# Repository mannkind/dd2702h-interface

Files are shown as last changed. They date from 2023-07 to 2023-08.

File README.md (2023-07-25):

# Home Automation - DD2702H

A **quick and dirty** interface to the DD2702H remote.

Seriously. This is hacky hack hacky. But it's all hidden in a nice little case, so I don't really care.  
It requires removing the DD2702H from the stock case, soldering some wires to it, and hooking up an esp32.

## Build of Materials

* 1 - DD2702H remote
* 1 - Custom PCB
* 1 - Nekmit Dual Port Ultra Thin Flat USB Wall Charger
* 1 - Wemos D1 Mini (esp32)
* 2 - Strips of female connectors for Wemos D1 Mini
* 3 - 1k through-hole resistors
* 3 - 2N3904 PNP transistors
* 1 - DD2702H Remote
* 11 - Male pins; angled preferred
* Some wires to connect them

## Program

The [example yaml](program/dd2702h.yaml) for ESPHome contains all you should need to get started. 
ESPHome is awesome, and I'm lazy.

## PCB

I ordered the PCB from OSHPark.com by uploading the KiCAD files.
Turn-around time was a week, and the boards from OSHPark are high quality.

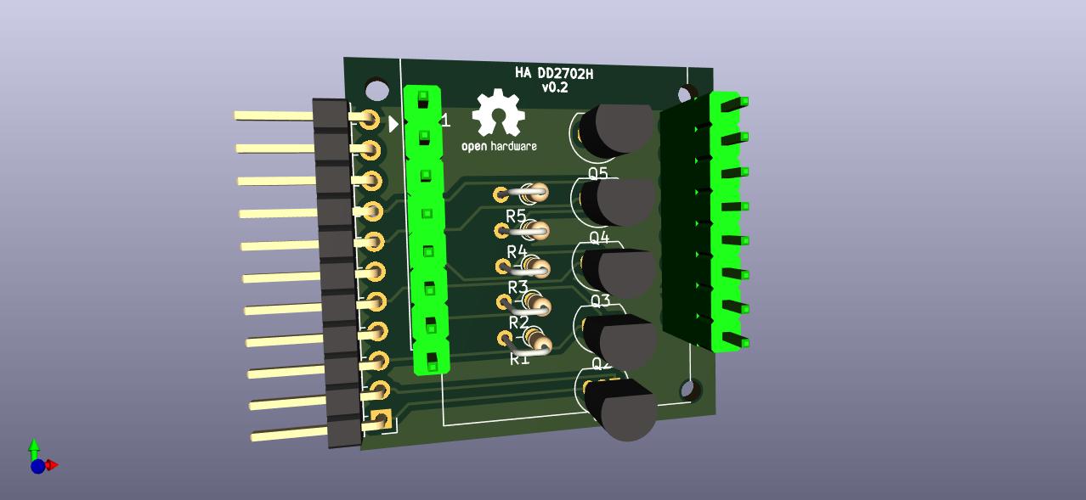
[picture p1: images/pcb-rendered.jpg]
rendered, populated pcb


## Case 

The case I've printed and am using is provided in the `case` folder as an `.stl` file. 
There's also the openscad source, if you're interested. It requires [YAPP_Box](https://github.com/mrWheel/YAPP_Box) to work.

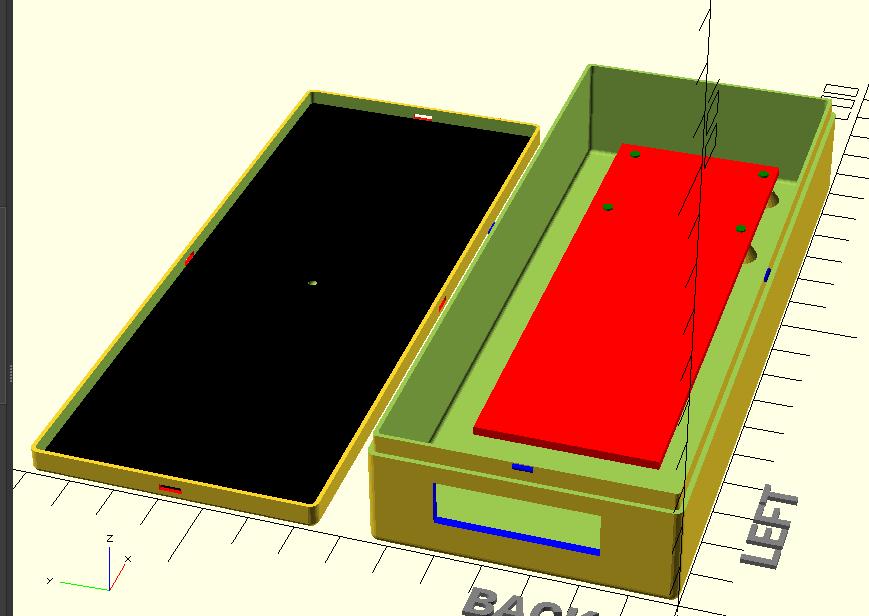
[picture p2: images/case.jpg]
rendered case


**Assembly Guide**

* Remove remote PCB from stock enclosure
* Solder wires to the up/stop/down buttons; optionally the channel buttons (I skipped the channel buttons)
* Solder ground wire to remote button battery holder
* Solder female pins into Wemos D1 Mini spot
* Solder resistors
* Solder transistors matching silkscreen
* Solder male header pins
* Solder wires to remote buttons as desired - one end should be a female connector
* Use electrical tape to hold the battery in position
* Use electrical tape to protect the bottom of the custom PCB
* Insert the remote PCB into the case; it should fit nicely on the pegs
* Place a dab of hotglue in the center; place the custom PCB on top of it
* Connect a USB cable to the Nekmit; hot glue that sucker down
* Put the lid on the case
* Plug into wall

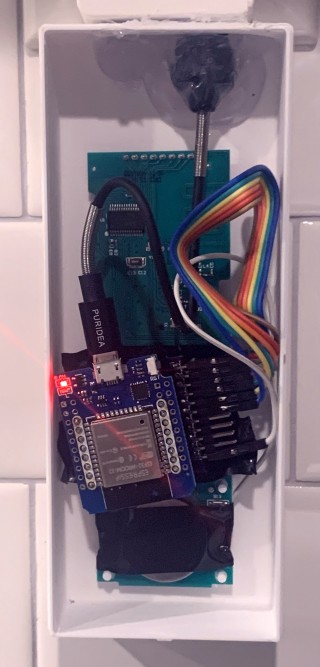
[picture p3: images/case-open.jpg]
image of the case + pcb

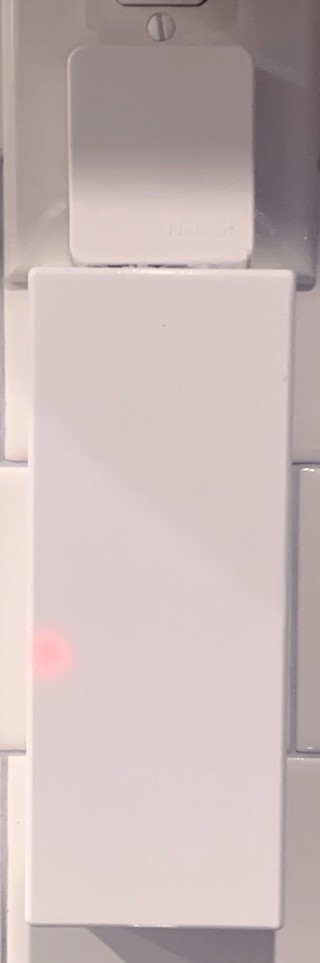
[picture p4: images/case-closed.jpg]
image of the case


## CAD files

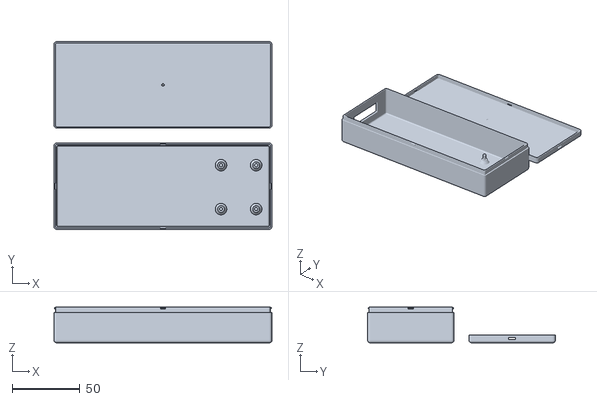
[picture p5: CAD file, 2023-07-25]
case/dd2702h.stl
161.5 x 139.0 x 26.5

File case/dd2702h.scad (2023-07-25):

//-----------------------------------------------------------------------
// Yet Another Parameterized Projectbox generator
//
//  This is a box for <template>
//
//  Version 1.8 (22-02-2023)
//
// This design is parameterized based on the size of a PCB.
//
//  for many or complex cutoutGrills you might need to adjust
//  the number of elements:
//
//      Preferences->Advanced->Turn of rendering at 100000 elements
//                                                  ^^^^^^
//
//-----------------------------------------------------------------------


polygonShape = [  [0,0],[20,15],[30,0],[40,15],[70,15]
                 ,[50,30],[60,45], [40,45],[30,70]
                 ,[20,45], [0,45]
               ];


include <../YAPP_Box/library/YAPPgenerator_v19.scad>

// Note: length/lengte refers to X axis, 
//       width/breedte to Y, 
//       height/hoogte to Z

/*
            padding-back>|<---- pcb length ---->|<padding-front
                                 RIGHT
                   0    X-ax ---> 
               +----------------------------------------+   ---
               |                                        |    ^
               |                                        |   padding-right 
             ^ |                                        |    v
             | |    -5,y +----------------------+       |   ---              
        B    Y |         | 0,y              x,y |       |     ^              F
        A    - |         |                      |       |     |              R
        C    a |         |                      |       |     | pcb width    O
        K    x |         |                      |       |     |              N
               |         | 0,0              x,0 |       |     v              T
               |   -5,0  +----------------------+       |   ---
               |                                        |    padding-left
             0 +----------------------------------------+   ---
               0    X-ax --->
                                 LEFT
*/

printBaseShell      = true;
printLidShell       = true;

// Edit these parameters for your own board dimensions
wallThickness       = 2.0;
basePlaneThickness  = 1.5;
lidPlaneThickness   = 1.5;

//-- Total height of box = basePlaneThickness + lidPlaneThickness 
//--                     + baseWallHeight + lidWallHeight
//-- space between pcb and lidPlane :=
//--      (bottonWallHeight+lidWallHeight) - (standoffHeight+pcbThickness)
baseWallHeight      = 25;
lidWallHeight       = 1;

// ridge where base and lid off box can overlap
// Make sure this isn't less than lidWallHeight
ridgeHeight         = 4;
ridgeSlack          = 0.2;
roundRadius         = 2;

// How much the PCB needs to be raised from the base
// to leave room for solderings and whatnot
standoffHeight      = 5.0;  //-- only used for showPCB
standoffPinDiameter = 2.5;
standoffHoleSlack   = 0.3;
standoffDiameter    = 5;

// Total height of box = basePlaneThickness + lidPlaneThickness 
//                     + baseWallHeight + lidWallHeight
pcbLength           = 122.50;
pcbWidth            = 40;
pcbThickness        = 2;
                            
// padding between pcb and inside wall
paddingFront        = 5;
paddingBack         = 30;
paddingRight        = 10;
paddingLeft         = 10;


//-- D E B U G -----------------//-> Default ---------
showSideBySide      = true;     //-> true
onLidGap            = 0;
shiftLid            = 1;
hideLidWalls        = false;    //-> false
colorLid            = "yellow";   
hideBaseWalls       = false;    //-> false
colorBase           = "white";
showOrientation     = true;
showPCB             = false;
showPCBmarkers      = false;
showShellZero       = false;
showCenterMarkers   = false;
inspectX            = 0;        //-> 0=none (>0 from front, <0 from back)
inspectY            = 0;        //-> 0=none (>0 from left, <0 from right)
//-- D E B U G ---------------------------------------

//-- pcb_standoffs  -- origin is pcb[0,0,0]
// (0) = posx
// (1) = posy
// (2) = standoffHeight
// (3) = flangeHeight
// (4) = flangeDiameter
// (5) = { yappBoth | yappLidOnly | yappBaseOnly }
// (6) = { yappHole, yappPin }
// (7) = { yappAllCorners | yappFrontLeft | yappFrondRight | yappBackLeft | yappBackRight }
pcbStands = [
      [117.75, 3.0, 3, 4, 9, yappBaseOnly, yappPin]
    , [117.75, 35.5, 3, 4, 9, yappBaseOnly, yappPin]
    , [91.75, 3, 3, 4, 9, yappBaseOnly, yappPin]
    , [91.75, 35.5, 3, 4, 9, yappBaseOnly, yappPin]
];     

//-- Lid plane    -- origin is pcb[0,0,0]
// (0) = posx
// (1) = posy
// (2) = width
// (3) = length
// (4) = angle
// (5) = { yappRectangle | yappCircle }
// (6) = { yappCenter }
cutoutsLid =  [

];

//-- base plane    -- origin is pcb[0,0,0]
// (0) = posx
// (1) = posy
// (2) = width
// (3) = length
// (4) = angle
// (5) = { yappRectangle | yappCircle }
// (6) = { yappCenter }
cutoutsBase =   [

];

//-- front plane  -- origin is pcb[0,0,0]
// (0) = posy
// (1) = posz
// (2) = width
// (3) = height
// (4) = angle
// (5) = { yappRectangle | yappCircle }
// (6) = { yappCenter }
cutoutsFront =  [
];

//-- back plane  -- origin is pcb[0,0,0]
// (0) = posy
// (1) = posz
// (2) = width
// (3) = height
// (4) = angle
// (5) = { yappRectangle | yappCircle }
// (6) = { yappCenter }
cutoutsBack =   [
    [(pcbWidth/2)-16, 0, 34, 10, 0, yappRectangle]
];

//-- left plane   -- origin is pcb[0,0,0]
// (0) = posx
// (1) = posz
// (2) = width
// (3) = height
// (4) = angle
// (5) = { yappRectangle | yappCircle }
// (6) = { yappCenter }
cutoutsLeft =   [

];

//-- right plane   -- origin is pcb[0,0,0]
// (0) = posx
// (1) = posz
// (2) = width
// (3) = height
// (4) = angle
// (5) = { yappRectangle | yappCircle }
// (6) = { yappCenter }
cutoutsRight =  [

];

//-- cutoutGrills    -- origin is pcb[x0,y0, zx]
// (0) = xPos
// (1) = yPos
// (2) = grillWidth
// (3) = grillLength
// (4) = gWidth
// (5) = gSpace
// (6) = gAngle
// (7) = plane {"base" | "lid" }
// (8) = {polygon points}}
cutoutsGrill = [
     // [0,  -5, 50, 40, 2, 2,  0, "base"] 
];

//-- connectors 
//-- normal         : origen = box[0,0,0]
//-- yappConnWithPCB: origen = pcb[0,0,0]
// (0) = posx
// (1) = posy
// (2) = pcbStandHeight
// (3) = screwDiameter
// (4) = screwHeadDiameter
// (5) = insertDiameter
// (6) = outsideDiameter
// (7) = flangeHeight
// (8) = flangeDiam
// (9) = { yappConnWithPCB }
// (10) = { yappAllCorners | yappFrontLeft | yappFrondRight | yappBackLeft | yappBackRight }
connectors   =  [

];
                

//-- base mounts -- origen = box[x0,y0]
// (0) = posx | posy
// (1) = screwDiameter
// (2) = width
// (3) = height
// (4..7) = yappLeft / yappRight / yappFront / yappBack (one or more)
// (5) = { yappCenter }
baseMounts   = [

];
               
//-- snap Joins -- origen = box[x0,y0]
// (0) = posx | posy
// (1) = width
// (2..5) = yappLeft / yappRight / yappFront / yappBack (one or more)
// (n) = { yappSymmetric }
snapJoins   =     [
      [(pcbWidth/2)+10, 4, yappFront]
    , [(pcbWidth/2)+10, 4, yappBack]
    , [((pcbLength+paddingFront+paddingBack)/2), 4, yappLeft]
    , [((pcbLength+paddingFront+paddingBack)/2), 4, yappRight]
];
               
//-- origin of labels is box [0,0,0]
// (0) = posx
// (1) = posy/z
// (2) = orientation
// (3) = plane {lid | base | left | right | front | back }
// (4) = font
// (5) = size
// (6) = "label text"
labelsPlane =  [

];


//========= MAIN CALL's ===========================================================
  
//===========================================================
module lidHookInside()
{
  //echo("lidHookInside(original) ..");
  
} // lidHookInside(dummy)
  
//===========================================================
module lidHookOutside()
{
  //echo("lidHookOutside(original) ..");
  
} // lidHookOutside(dummy)

//===========================================================
module baseHookInside()
{
  //echo("baseHookInside(original) ..");
  
} // baseHookInside(dummy)

//===========================================================
module baseHookOutside()
{
  //echo("baseHookOutside(original) ..");
  
} // baseHookOutside(dummy)




//---- This is where the magic happens ----
YAPPgenerate();

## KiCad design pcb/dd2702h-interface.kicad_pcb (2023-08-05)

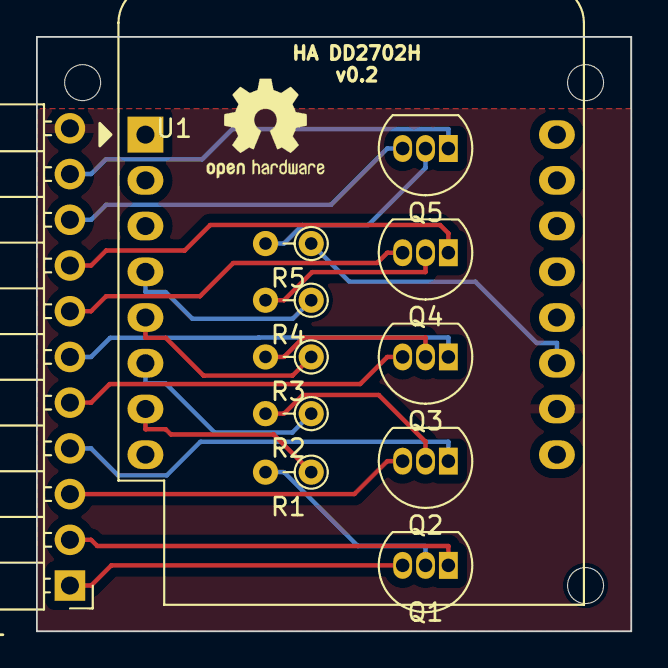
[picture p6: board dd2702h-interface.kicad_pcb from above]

Board: 2 copper layers, 33.0 x 33.0 mm, 12 parts (0 on the bottom side), 21 nets.

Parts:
J1: Conn_01x11_Pin; PinHeader_1x11_P2.54mm_Horizontal
Q1, Q2, Q3, Q4, Q5: 2N3904; TO-92_Inline
R1, R2, R3, R4, R5: R_US; R_Axial_DIN0204_L3.6mm_D1.6mm_P2.54mm_Vertical
U1: WeMos_D1_mini; WEMOS_D1_mini_light

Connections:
CH_DOWN_C: J1.7, Q4.3 (C)
CH_DOWN_E: J1.8, Q4.1 (E)
CH_UP_C: J1.9, Q5.3 (C)
CH_UP_E: J1.10, Q5.1 (E)
DOWN_C: J1.5, Q3.3 (C)
DOWN_E: J1.6, Q3.1 (E)
GND: J1.11, U1.10 (GND)
GPIO2: R5.1, U1.11 (D4)
GPIO12: R3.1, U1.5 (MISO/D6)
GPIO13: R2.1, U1.6 (MOSI/D7)
GPIO14: R4.1, U1.4 (SCK/D5)
GPIO15: R1.1, U1.7 (CS/D8)
unnamed: Q1.2 (B), R1.2
unnamed: Q2.2 (B), R2.2
unnamed: Q3.2 (B), R3.2
unnamed: Q4.2 (B), R4.2
unnamed: Q5.2 (B), R5.2
STOP_C: J1.3, Q2.3 (C)
STOP_E: J1.4, Q2.1 (E)
UP_C: J1.1, Q1.3 (C)
UP_E: J1.2, Q1.1 (E)

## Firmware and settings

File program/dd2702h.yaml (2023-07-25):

substitutions:
  slug: dd2702h
  name: DD2702H

esphome:
  name: ${slug}

esp32:
  board: wemos_d1_mini32

wifi:
  ssid: !secret wifi_ssid
  password: !secret wifi_password

api:

logger:
  level: info

ota:

# Individual sensors
output:
  - platform: gpio
    id: ch_up
    pin:
      number: GPIO16

  - platform: gpio
    id: ch_down
    pin:
      number: GPIO18

  - platform: gpio
    id: down
    pin:
      number: GPIO19

  - platform: gpio
    id: stop
    pin:
      number: GPIO23

  - platform: gpio
    id: up
    pin:
      number: GPIO5

button:
  - platform: output
    name: ${name} Up
    output: up
    duration: 500ms

  - platform: output
    name: ${name} Down
    output: down
    duration: 500ms

  - platform: output
    name: ${name} Stop
    output: stop
    duration: 500ms

  - platform: output
    name: ${name} Channel Down
    output: ch_down
    duration: 500ms

  - platform: output
    name: ${name} Channel Up
    output: ch_up
    duration: 500ms

  - platform: restart
    name: ${name} Restart

binary_sensor:
  - platform: status
    name: ${name} Status

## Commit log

2023-08-05 Mounting holes; autorouted
    [dd2702h-interface.kicad_pcb]
2023-08-05 Add the case w/pcb rendered
